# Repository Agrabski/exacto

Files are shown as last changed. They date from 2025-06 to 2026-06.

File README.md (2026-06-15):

Exacto
======

Rust project for the _Arduino Nano_, powering a reflex sight for airsoft guns with an integrated ballistic computer.

## Build Instructions
1. Install prerequisites as described in the [`avr-hal` README] (`avr-gcc`, `avr-libc`, `avrdude`, [`ravedude`]).

2. Run `cargo build` to build the firmware.

3. Run `cargo run` to flash the firmware to a connected board.  If `ravedude`
   fails to detect your board, check its documentation at
   <https://crates.io/crates/ravedude>.

4. `ravedude` will open a console session after flashing where you can interact
   with the UART console of your board.

[`avr-hal` README]: https://github.com/Rahix/avr-hal#readme
[`ravedude`]: https://crates.io/crates/ravedude

## License
Licensed under the GNU General Public License, Version 3 or (at your option)
any later version ([LICENSE](LICENSE) or <https://www.gnu.org/licenses/gpl-3.0.html>).

## Contribution
Unless you explicitly state otherwise, any contribution intentionally submitted
for inclusion in the work by you shall be licensed under the GPL-3.0 license,
without any additional terms or conditions.

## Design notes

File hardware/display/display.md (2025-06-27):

| Pin  | Description |
|---|---|
| RES  | Reset, low active |
| DC | Data/Command selection (high for data, low for command) |
| CS | Chip selection, low active |
| CLK  | Clock input |
| DIN  | Data input |
| GND  | Ground |
| VCC  | Power (3.3V / 5V input) |

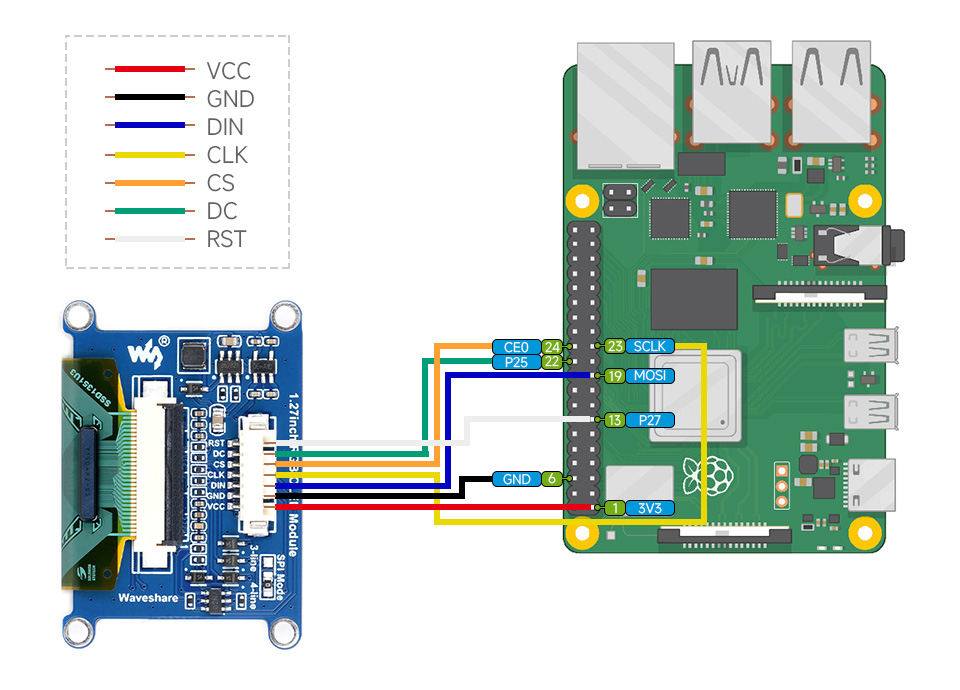
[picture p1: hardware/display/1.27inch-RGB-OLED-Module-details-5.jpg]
Display Pinout Diagram


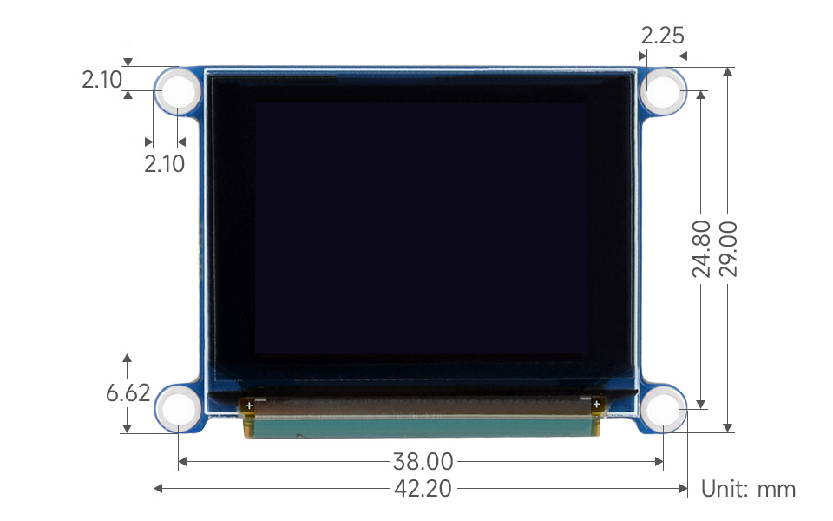
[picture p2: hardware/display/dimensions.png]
Display dimensions


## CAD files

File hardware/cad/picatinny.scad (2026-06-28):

// ============================================================
// Picatinny rail connector — MIL-STD-1913  (TWO-PART clamp)
//
//   picatinny_clamp_body(length)  female clamp FIXED half — ceiling +
//                             right (fixed) jaw + recoil lug.  Built
//                             "hanging": its flat MOUNTING FACE is at z=0
//                             and it extends DOWN, so it unions straight
//                             onto the underside of a part at z=0.
//   picatinny_clamp_bar(length)   the separate, removable LEFT jaw.  Two
//                             cross-bolts pull it toward the body.
//
// The clamp CAPTURES the rail's dovetail: the rail is widest at the 45°
// clamping shoulders, with an undercut below.  Both jaws hook under that
// undercut so the rail can't drop out.  Mounting (mid-rail, no end needed):
// hook the fixed right jaw on the rail, swing the rail up under the
// ceiling, fit the bar onto the left shoulder, then tighten the 2 cross-
// bolts (heads on the bar, running ALL THE WAY THROUGH the clamp into
// brass inserts pressed into the far/outer face of the body) to clamp.
// A recoil lug drops into a transverse slot to take recoil.
// ============================================================

// ── MIL-STD-1913 profile (widest at the shoulders, undercut below) ──
pic_width      = 21.20;  // max width across the clamping shoulders
pic_top_w      = 15.60;  // width of the top flat
pic_body_w     = 15.60;  // width of the rail body / neck (below undercut)
pic_bevel      = (pic_width - pic_top_w) / 2;   // 2.80, 45° run
pic_neck_z     =  1.00;  // body height below the undercut
pic_shoulder_z = pic_neck_z + pic_bevel;        // 3.80, widest clamping line
pic_top_z      = pic_shoulder_z + pic_bevel;    // 6.60, rail top
pic_slot_w     =  5.35;  // recoil-groove width
pic_slot_pitch = 10.00;  // recoil-groove pitch
pic_slot_depth =  2.00;  // recoil-groove depth from the top flat

// ── Clamp / fit ──────────────────────────────────────────────
pic_clear     = 0.30;    // slide-fit clearance on the channel
pic_ceil_t    = 5.00;    // ceiling thickness above the rail top
                         // (tall enough for the cross-bolts to run through)
pic_jaw_t     = 6.00;    // side-jaw thickness
pic_clamp_w   = pic_width + 2 * pic_jaw_t;   // 33.20 overall clamp width
pic_clamp_top = pic_top_z + pic_ceil_t;      // 11.60 mount-face height

// Two-part split: a vertical plane at the rail's left-top edge separates
// the removable bar (left) from the fixed body (right).
pic_split_x   = -pic_top_w / 2;  // -7.80 mating plane
pic_split_gap = 0.50;            // gap so the bolts can draw the bar inward

// Cross-bolts (2): head on the bar (outer left), the bolt runs all the way
// through the bar AND the body, and threads into a brass insert pressed into
// the body's outer (right) face — on the opposite side from the bolt head.
pic_bolt_clear     = 4.30;  // M4 through-bolt clearance (bar + body)
pic_bolt_insert_d  = 6.00;  // M4 brass insert OD (far face of body)
pic_bolt_insert_depth = 6.00;

// Locating pins (2): round bosses on the body's mating face that drop into
// clearance holes in the bar.  They fix the bar's fore/aft (Y) and vertical
// (Z) position relative to the body, so the two clamp halves can't shift out
// of alignment — while still letting the cross-bolts draw the bar inward (X).
pic_loc_pin_d   = 3.00;   // boss diameter
pic_loc_pin_len = 4.00;   // protrusion from the body mating face
pic_loc_clear   = 0.25;   // radial clearance of the bar's locating hole

$fn = 48;

// Rail cross-section (X = width, second coord = height above base).
// Body -> flare OUT to the widest shoulder (undercut) -> bevel IN to top.
function _pic_profile() = [
  [-pic_body_w / 2, 0],
  [ pic_body_w / 2, 0],
  [ pic_body_w / 2, pic_neck_z],
  [ pic_width / 2, pic_shoulder_z],
  [ pic_top_w / 2, pic_top_z],
  [-pic_top_w / 2, pic_top_z],
  [-pic_width / 2, pic_shoulder_z],
  [-pic_body_w / 2, pic_neck_z],
];

// Extrude the (optionally grown) rail profile along +Y, base at z=0.
module _pic_extrude(length, grow = 0) {
  translate([0, length, 0])
    rotate([90, 0, 0])
      linear_extrude(height = length)
        offset(r = grow)
          polygon(_pic_profile());
}

// Bolt height: mid-way up the ceiling band (above the rail top, so the
// bolts run through solid material clear of the channel).
function _pic_bolt_z() = pic_top_z + pic_ceil_t / 2;

// Locating-pin Y positions — shared by the body (bosses) and the bar
// (clearance holes) so they always line up.  Kept well clear of the bolts.
function _pic_loc_yy(length) = [length * 0.15, length * 0.85];

// Whole (un-split) clamp solid in "up" coords: jaw+ceiling block minus the
// rail channel, plus the recoil lug.
module _clamp_solid_up(length) {
  difference() {
    translate([-pic_clamp_w / 2, 0, pic_neck_z])
      cube([pic_clamp_w, length, pic_clamp_top - pic_neck_z + 0.2]);
    translate([0, -1, 0]) _pic_extrude(length + 2, pic_clear);
  }
  // recoil lugs — one tooth per rail slot, as many as fit at the slot
  // pitch, centred along the length (all stay with the fixed body)
  lug_w  = pic_slot_w - 2 * pic_clear;
  n_lugs = max(1, floor((length - lug_w) / pic_slot_pitch) + 1);
  for (i = [0 : n_lugs - 1])
    translate([-6,
               length / 2 + (i - (n_lugs - 1) / 2) * pic_slot_pitch - lug_w / 2,
               pic_top_z - pic_slot_depth + pic_clear])
      cube([12, lug_w, pic_slot_depth + 0.6]);
}

// ── Fixed body (hanging: mount face at z=0, body below) ──────
module picatinny_clamp_body(length) {
  bolt_z = _pic_bolt_z();
  translate([0, 0, -pic_clamp_top + 0.2]) {
    difference() {
      // keep everything right of the split plane (+ gap)
      intersection() {
        _clamp_solid_up(length);
        translate([pic_split_x + pic_split_gap, -1, pic_neck_z - 1])
          cube([pic_clamp_w, length + 2, pic_clamp_top + 2]);
      }
      for (yy = [length * 0.28, length * 0.72]) {
        // through-bolt clearance: from the mating face all the way out the
        // far (right) face, so the screw passes fully through the body
        translate([pic_split_x - 1, yy, bolt_z])
          rotate([0, 90, 0]) cylinder(d = pic_bolt_clear, h = pic_clamp_w);
        // brass insert pressed into the OUTER (right) face — opposite the head
        translate([pic_clamp_w / 2 - pic_bolt_insert_depth, yy, bolt_z])
          rotate([0, 90, 0]) cylinder(d = pic_bolt_insert_d, h = pic_bolt_insert_depth + 0.2);
      }
    }
    // locating bosses — protrude from the mating face toward the bar
    for (yy = _pic_loc_yy(length))
      translate([pic_split_x + pic_split_gap, yy, bolt_z])
        rotate([0, -90, 0]) cylinder(d = pic_loc_pin_d, h = pic_loc_pin_len);
  }
}

// ── Removable bar / left jaw (same coord frame as the body) ──
module picatinny_clamp_bar(length) {
  bolt_z = _pic_bolt_z();
  translate([0, 0, -pic_clamp_top + 0.2])
    difference() {
      // keep everything left of the split plane
      intersection() {
        _clamp_solid_up(length);
        translate([-pic_clamp_w / 2 - 1, -1, pic_neck_z - 1])
          cube([pic_split_x - (-pic_clamp_w / 2 - 1), length + 2, pic_clamp_top + 2]);
      }
      // bolt clearance (head bears on the outer left face — no counterbore)
      for (yy = [length * 0.28, length * 0.72])
        translate([-pic_clamp_w / 2 - 0.1, yy, bolt_z])
          rotate([0, 90, 0]) cylinder(d = pic_bolt_clear, h = pic_clamp_w / 2 + 2);
      // locating holes — receive the body's bosses; bored deeper than the
      // boss reaches so the bolts can still pull the bar fully inward
      for (yy = _pic_loc_yy(length))
        translate([pic_split_x + pic_split_gap, yy, bolt_z])
          rotate([0, -90, 0])
            cylinder(d = pic_loc_pin_d + 2 * pic_loc_clear,
                     h = pic_split_gap + pic_loc_pin_len + 1.0);
    }
}

// ── Demo (ignored when this file is `use`d) ──────────────────
picatinny_clamp_body(40);
color("orange") picatinny_clamp_bar(40);

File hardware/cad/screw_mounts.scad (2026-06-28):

// ============================================================
// Screw mounts — reusable brass-insert + screw-hole cutters
//
// Two negative-geometry modules, meant to be subtracted (difference())
// from a part.  They are the matched halves of one fastened joint:
//
//   insert_hole(size)        bore for a brass heat-set insert, pressed
//                            into the part that the screw threads INTO.
//   screw_hole(size, length) clearance hole in the COMPLEMENTARY part the
//                            screw passes THROUGH — exact screw-body bore
//                            that tapers out (countersink) into the head.
//
// `size` is "M2" or "M3".  Dimensions for the inserts match those already
// used in sight_housing.scad (M2: ø3.20 × 4.0; M3: ø4.00 × 5.0).
//
// Orientation convention (both modules):
//   The mouth of the hole sits at the LOCAL ORIGIN on the Z=0 plane and
//   the hole bores DOWNWARD into -Z, i.e. the fastener is imagined entering
//   from +Z.  Each cutter pokes +0.1 mm past Z=0 so the Boolean cleanly
//   breaks the surface.  translate()/rotate() the call to place it on the
//   real face, exactly like the bores in sight_housing.scad.
//
//   insert_hole : insert is pressed in from +Z; bore is +Z-deep into stock.
//   screw_hole  : head sits flush at Z=0 (countersunk), body bores to -Z.
// ============================================================

// ── Fastener table ───────────────────────────────────────────
// One row per screw size.  Head thickness is the user-specified value
// (M3 = 1.75 mm, M2 = 1.50 mm); head diameter is the user-specified
// countersunk flat-head OD (M3 = 5.8, M2 = 4.0).  Body diameter is the
// nominal thread OD — the screw hole uses this EXACTLY (see screw_hole()).
function screw_body_d(size) =
  size == "M3" ? 3.00 :
  size == "M2" ? 2.00 : undef;

function screw_head_d(size) =
  size == "M3" ? 5.80 :
  size == "M2" ? 4.00 : undef;

function screw_head_t(size) =
  size == "M3" ? 1.75 :
  size == "M2" ? 1.50 : undef;

// Brass heat-set insert bore (outer dia + length) — values shared with
// sight_housing.scad's insert_d / insert_depth (M2) and join_insert_d /
// join_insert_depth (M3).
function insert_bore_d(size) =
  size == "M3" ? 4.00 :
  size == "M2" ? 3.20 : undef;

function insert_bore_depth(size) =
  size == "M3" ? 5.00 :
  size == "M2" ? 4.00 : undef;

// ── Brass-insert bore ────────────────────────────────────────
// Pocket for a heat-set insert, pressed in from +Z.  Bores `depth` into
// -Z (default = the size's standard insert length) and pokes 0.1 mm past
// the Z=0 face so the cut breaks the surface cleanly.
//   depth : override the bore depth (mm).  Leave default for the standard
//           insert length.
module insert_hole(size, depth = undef) {
  d = insert_bore_d(size);
  h = depth == undef ? insert_bore_depth(size) : depth;
  translate([0, 0, -h])
    cylinder(d = d, h = h + 0.1);
}

// ── Screw clearance hole + head countersink ──────────────────
// Cut in the complementary part the screw passes THROUGH.  The straight
// bore is EXACTLY the screw-body diameter (plus optional `clearance`,
// default 0 — a true body-diameter hole as requested); the top
// screw_head_t(size) mm flares out as a cone from the body diameter up to
// the full head diameter, so a countersunk head seats flush at Z=0.
//   length    : straight body-bore length below the taper (mm).  Set to
//               the wall/material thickness the screw shank crosses; the
//               taper sits on top of this, the bore pokes 0.1 mm past the
//               far side for a clean break.
//   clearance : added to the body diameter (mm).  Default 0 = exact body
//               diameter.  Use e.g. 0.4 for a free-fit clearance hole.
module screw_hole(size, length, clearance = 0) {
  bd = screw_body_d(size) + clearance; // straight bore = exact body dia (+fit)
  hd = screw_head_d(size);             // countersink mouth = head dia
  ht = screw_head_t(size);             // taper height = head thickness

  union() {
    // straight body-clearance bore, hanging below the taper
    translate([0, 0, -(length + ht)])
      cylinder(d = bd, h = length + 0.1);
    // head countersink: cone flaring from body dia up to head dia
    translate([0, 0, -ht])
      cylinder(d1 = bd, d2 = hd, h = ht);
    // break the top surface above the head mouth
    translate([0, 0, -0.001])
      cylinder(d = hd, h = 0.1);
  }
}

// ── Demo (only renders when this file is opened directly; `use <>`
// imports the modules/functions above and ignores everything below) ──
$fn = 48;
demo_block = 14;
// left: a block with an M3 insert bore;  right: a block with an M3 screw
// hole, sliced so the countersink + body bore are visible.
difference() {
  translate([-demo_block - 2, -demo_block / 2, -demo_block])
    cube([demo_block, demo_block, demo_block]);
  insert_hole("M3");
}
difference() {
  translate([2, -demo_block / 2, -demo_block])
    cube([demo_block, demo_block, demo_block]);
  translate([2 + demo_block / 2, 0, 0])
    screw_hole("M3", demo_block - 4);
}

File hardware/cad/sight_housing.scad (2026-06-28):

// ============================================================
// Exacto Reflex Sight Housing — v5 (EOTech-style, two-part, birdbath optics)
//
// Two screw-joined parts, split at the seam z = body_height (20 mm), PLUS a
// detachable front-lens cartridge:
//   bottom_part()        display holder = screen_body() + joint inserts
//   top_part()           optics holder  = eotech_shroud() + beamsplitter_mount()
//                                         + combiner_index_stops()
//   combiner_cartridge() removable front lens = combiner_frame() + side ears,
//                        bolted into the top part's front channel by 4 side M3
//                        screws and depth-located by 3 rear indexing stops.
//
// Sub-modules:
//   screen_body()         box holding OLED + electronics, display up
//   eotech_shroud()       rectangular window frame — left/right walls,
//                         top hood, front/rear lower lips, sized to
//                         enclose BOTH optics frames
//   beamsplitter_frame()  flat 30/70 plate frame at `beamsplitter_tilt` deg
//   combiner_frame()      curved partial-mirror ("combiner") frame, fixed
//                         vertical (`combiner_tilt` = 90°)
//   beamsplitter_mount()  / combiner_mount()  position each frame in world
//                         space (side arms overlap the frame and merge
//                         into the shroud side walls, same idiom as v4)
//
// Optics — true birdbath, two elements, each hit EXACTLY ONCE (replaces
//   both the v4 single curved combiner lens AND the earlier "same panel
//   hit twice" birdbath topology):
//   display (face up) -> flat 30/70 beamsplitter, fixed 45° relay (1st &
//   only hit) -> curved partial-mirror combiner, fixed VERTICAL 90°
//   (2nd & only hit, exact retro-reflection back the way it came) -> eye,
//   looking back THROUGH the combiner's see-through window.  Both tilts
//   are fixed constants now — no derivation, no sweep.  See the
//   "Birdbath optics" parameter block below for the exact ray-trace.
//
// Joint: the top part's side walls drop below the seam as SKIRTS that lap
//   over rebates on the bottom part's thick side edges.  4 horizontal M3
//   screws (2 per side), placed LOW — under the PCB, in the solid lower
//   body — pin and clamp the lap.  Use M3 x ~12 mm into brass inserts.
//   The left/right edges are thickened (side_edge) to host the inserts.
//
// Forward box: a hollow electronics enclosure extends from the optics head
//   toward the muzzle (box_length), full width, up to the lens-opening
//   height, with a screw-on top lid.  Cable routes UNDER the PCB to a plug
//   opening in the box front face.
//
// Mount: a female MIL-STD-1913 Picatinny clamp (picatinny.scad) is fused
//   to the underside and runs the WHOLE length of the sight.
//
// Optics retention: friction fit in the frame pockets + adhesive.  The
// beamsplitter frame is fused into the top part; the COMBINER frame is a
// detachable cartridge (combiner_cartridge()) bolted in from the sides, so the
// front lens can be serviced/swapped without reprinting the optics head.
//
// Set `render_part` below to choose what to render/export.
//
// Display: Waveshare 1.27-inch SSD1351 RGB OLED
//   PCB     42.20 × 29.00 mm  (hardware/display/dimensions.png)
//   Active  38.00 × 24.80 mm
//   Holes   ø2.10, inset 2.25 mm (X) / 2.10 mm (Y) from PCB edge
//
// Birdbath optics (replaces both the old single curved meniscus combiner
// AND the earlier two-hit-same-panel birdbath):
//   Beamsplitter: flat 30/70 reflective sheet, beamsplitter_optic_width x
//                 beamsplitter_optic_height, FIXED 45° relay near the
//                 display — redirects the vertical beam to exactly
//                 horizontal, nothing more.
//   Combiner:     curved partial mirror, combiner_optic_width x
//                 combiner_optic_height, single cylindrical curvature
//                 combiner_radius, FIXED VERTICAL (combiner_tilt = 90°) —
//                 the element the eye actually looks through, both for the
//                 real target and the reflected reticle.
//   See the "Birdbath optics" parameter block for the full derivation.
// ============================================================

// ┌─────────────────────────────────────────────────────────────┐
// │  beamsplitter_tilt = beamsplitter tilt from horizontal —      │
// │  FIXED at 45°.  combiner_tilt = combiner tilt — FIXED at 90°  │
// │  (vertical).  Both are pinned per explicit design decision    │
// │  (topology "c") — NOT reprint-tunable sweep parameters any    │
// │  more.  Changing either invalidates the whole fold derivation │
// │  below.                                                       │
// └─────────────────────────────────────────────────────────────┘
use <picatinny.scad>
use <screw_mounts.scad>

beamsplitter_tilt = 45; // beamsplitter tilt from horizontal, deg — FIXED, do not sweep (was 35–65 in the rejected topology)

// Which piece to render/export: "both" (assembled), "top", "bottom",
// "combiner" (detachable front-lens cartridge), "bar" (removable Picatinny
// clamp jaw), "lid" (box top lid)
render_part = "both";

// Forward electronics box (extends from the optics head toward the muzzle).
box_length = 80.00; // box length, front-to-rear (8 cm)

// ── Display (Waveshare 1.27" SSD1351 OLED) ───────────────────
display_pcb_width = 42.20; // OLED carrier PCB width  (X)
display_pcb_height = 29.00; // OLED carrier PCB height (Y)
display_pcb_thickness = 1.80; // OLED carrier PCB thickness (Z)
display_active_width = 38.00; // visible/active screen width  (X)
display_active_height = 24.80; // visible/active screen height (Y)
display_hole_dia = 2.10; // PCB clearance-hole dia (datasheet); not used for body bores
display_hole_inset_x = 2.25; // mounting-hole inset from the PCB edge, X
display_hole_inset_y = 2.10; // mounting-hole inset from the PCB edge, Y
display_fit_clearance = 0.10; // gap on EVERY side of the OLED PCB in its pocket (X/Y edges + Z floor)

// ── Fasteners ────────────────────────────────────────────────
// All screw/insert geometry now comes from screw_mounts.scad — its
// insert_hole()/screw_hole() cutters plus the shared M2/M3 fastener table
// are the single source of truth (no local diameter/depth constants).
//   PCB        : M2, screw from the top into inserts below the pocket.
//   Part joint : M3, 4 horizontal screws through the skirts into edge inserts.
//   Box lid    : M3, 4 vertical screws through the lid into boss inserts.
m3_clearance_fit = 0.40; // added to the M3 body dia for a free-fit through-hole (skirts + lid)
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

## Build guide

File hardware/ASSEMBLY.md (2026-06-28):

# Exacto Reflex Sight — Parts List & Assembly

Build guide for the **XM-1E1** housing
defined in [`cad/sight_housing.scad`](cad/sight_housing.scad).

> **Versioning:** `XM-<gen>E<rev>`. The `E<rev>` number is incremented
> **only after a revision has been sent to print** — not on ordinary design
> edits. Current revision: **XM-1E1**.

The sight is a two-part printed housing that holds a small OLED, folds its
image through a birdbath relay (flat beamsplitter → curved partial-mirror
combiner), and clamps to a MIL-STD-1913 Picatinny rail. All electronics
other than the display live in a forward box with a removable lid.

Overall envelope: **58.2 mm wide × 114 mm long × ~50 mm tall** (rail clamp
adds ~11.6 mm below).

---

## 1. Printed parts

Export each by setting `part=` at the top of `sight_housing.scad` (or
`openscad -D 'part="…"'`) and slicing the resulting STL.

| `part` | Component | Qty | Notes |
|---|---|-----|---|
| `bottom` | Bottom part — display holder + forward electronics box + **fixed** Picatinny jaw | 1 | Hosts the OLED pocket, cable channel, and all brass inserts except the lid/combiner |
| `top` | Top part — optics shroud + beamsplitter mount + combiner mount | 1 | Holds both optical elements |
| `bar` | Picatinny clamp bar (removable left jaw) | 1 | Pulled in by 2 cross-bolts |
| `lid` | Forward-box top lid | 1 | Screws onto the box bosses |

`part="both"` renders the full assembled preview (all four parts in place)
for checking fit; it is not a printable export.

### Print recommendations
- Material: PLA/PETG (PETG or ABS/ASA if the sight will see sun/heat).
- Layer height ≤ 0.2 mm around the optic pockets for a clean friction fit.
- Suggested orientation: print **bottom** and **top** on their flat seam
  face (z = 20 mm split plane) so the lap joint and insert bores come out
  true; print the **lid** flat; print the **bar** on its outer flat face.
- The combiner pocket has a shallow (~1 mm) cylindrical curve — no supports
  needed, but don't over-extrude or the optic won't seat flat.

---

## 2. Optical elements (not printed)

| Item | Size | Qty | Notes |
|---|---|-----|---|
| Plate beamsplitter, 30/70 (R/T) | 32 × 30 mm, 2.0 mm thick | 1 | Flat sheet. Drops into the angled (45°) frame pocket from the front (+Y) face |
| Collimating combiner lens | 34 × 24 mm stadium (rounded R16.97 ends), 2.74 mm thick | 1 | The previously-used lens ([`lens/lense.avif`](lens/lense.avif)). Sits vertical; drops into the front cartridge pocket from the front (+Y) face |

Both are retained by friction fit in their pockets **plus adhesive** (no set
screws — the merged side arms bury any screw access). A ~1.5 mm rim laps each
optic at the rear; the eye looks straight through both windows.

### Recommended / DIY materials

A true cylindrical R≈120 mm partial-mirror combiner is not a common catalog
part, so the optics are the part that drives sourcing. Cheap, hobby-tool
options below; all are knife/scorer/heat-gun workable with no custom optics
order (total optics cost ~$15–30).

**Beamsplitter (flat — the easy one):**
- **Best match:** 70/30 (or 30/70) **teleprompter glass** — dielectric
  partial-mirror film on glass. Score and snap to 32 × 30 mm. ~2 mm thick,
  which matches the pocket. ~$10–20.
- **Cheaper alt:** **two-way ("one-way") mirror acrylic** — saw/laser
  cuttable, won't shatter. Reflectivity is nearer 50/50 and less spectrally
  even, but fine for a prototype. ~$5–15.
- If using thin film-on-PET, laminate it to a 2.0 mm clear carrier so it
  seats flush under the retaining lip. Avoid fragile pellicle beamsplitters
  for a DIY build.
- **Orientation (ghost suppression):** teleprompter glass is partially
  reflective on one face and AR-coated on the other. Mount it with the
  **AR-coated face outward** (toward the real world) so the second surface
  doesn't throw a ghost/double image. This is the standard DIY-AR (Project
  North Star) practice.

**Combiner (curved partial mirror — the hard one):**
- **Recommended DIY:** thermoform **two-way mirror acrylic** over a
  3D-printed **R = 120 mm convex cylindrical (or spherical) form**. Heat to
  ~120–160 °C (heat gun / oven) and slump. Sag over the 32 mm aperture is
  only ~1.07 mm, so the curve is gentle and forgiving. Reflective face goes
  **concave / rear** (−Y) per Step 2 below.
- **Acceptable substitute:** a **spherical** R≈120 mm partial mirror — over a
  32 mm window the difference from cylindrical is minor and spherical forms
  are easier to make/buy.
- **Exact but not cheap:** the serious DIY-AR route. Either a
  cylindrical/spherical concave mirror R = 120 mm (f ≈ 60 mm) with a partial
  coating from an optics supplier (Edmund/Thorlabs), or a **CNC / diamond-
  turned solid PMMA reflector** (the method Leap Motion's Project North Star
  uses, and what vendors like CombineReality / Smart Prototyping sell). Tens
  of dollars plus likely a custom coating, but the surface accuracy is what
  makes the image distortion-free.
  - **How to obtain one (made to spec):** there is no off-the-shelf optic
    for this surface — ready-made AR combiners (e.g. Project North Star
    reflectors) are large freeform/ellipsoidal parts and do **not** match the
    32 × 32 mm, R = 120 mm cylinder, so don't try to adapt one. Instead,
    export the combiner surface from
    [`cad/sight_housing.scad`](cad/sight_housing.scad) as a STEP/STL and send
    it to an online CNC service (PCBWay, Xometry, Protolabs, or a local shop)
    requesting **optical-grade PMMA, machined then vapor-polished** for the
    32 × 32 mm, R = 120 mm concave face. Finish with a partial-mirror
    treatment: a sputter/optics house can apply a real beamsplitter coating,
    or for a budget build apply two-way mirror film / a light spray-on
    "mirror tint" to the convex rear face. Diamond-turning gives the best
    surface but needs a specialist shop (e.g. a custom-optics fabricator) and
    raises cost into the hundreds.
- **Salvage:** curved combiners from dead red-dot sights or cheap car-HUD
  reflectors are already partial mirrors, but their radius won't be 120 mm —
  only viable if you re-derive the optical block.

> **Important:** the model's ~50 mm eye relief and reticle collimation assume
> the **120 mm combiner radius** and the **concave-rear** orientation.
> Substituting a different curve (e.g. a salvaged combiner) invalidates the
> fold; re-check the optical block in
> [`cad/sight_housing.scad`](cad/sight_housing.scad) first.
>
> Combiner reflectivity is a trade-off: too high dims the see-through target,
> too low washes out the reticle. Two-way acrylic (~50/50) is a fine starting
> point — tune by swapping film/coating grades.
>
> **Ghosting:** a thermoformed two-way-acrylic combiner has no AR coating on
> either face, so expect some secondary (ghost) reflection — the known cost
> of the cheap route. DIY-AR builds (Project North Star) AR-coat the outer
> (convex) combiner face to kill it; a CNC/bought reflector can come coated.
> The small 32 mm aperture and gentle R = 120 mm curve keep distortion low,
> which is the one thing working in the thermoform route's favor.

---

## 3. Electronics

| Item | Qty | Notes |
|---|-----|---|
| Waveshare 1.27" SSD1351 RGB OLED module | 1 | PCB 42.20 × 29.00 mm; active area 38.0 × 24.80 mm faces up |
| Microcontroller (Arduino Nano or equiv.) | 1 | Lives in the forward box; `body_height` is sized for a Nano + wiring |
| Battery + USB / power board | 1 | Forward box; cable exits the box front plug opening (14 × 9 mm) |
| Ribbon/flying lead, OLED → MCU | 1 | Routes **under** the PCB, down the cable channel, into the forward box |

---

## 4. Fasteners

All screws are **countersunk (flat-head)** except the PCB screws (head bears
on the PCB) and the Picatinny cross-bolts (head bears on the bar's outer
face). Insert bores and countersinks are generated by
[`cad/screw_mounts.scad`](cad/screw_mounts.scad) and `cad/picatinny.scad`.

| Joint | Screw | Qty | Brass heat-set insert | Qty |
|---|---|-----|---|-----|
| PCB → body | M2 pan/cheese-head × **8 mm** | 4 | M2 (ø3.2 × 4 mm bore) | 4 |
| Top ↔ bottom side joint | M3 countersunk × **12 mm** (horizontal, 2 per side) | 4 | M3 (ø4.0 × 5 mm bore) | 4 |
| Forward-box lid | M3 countersunk × **12 mm** (vertical) | 2 | M3 (ø4.0 × 5 mm bore) | 2 |
| Picatinny clamp cross-bolts | M4 socket-cap × ~16 mm (horizontal) | 2 | M4 (ø6.0 × 6 mm bore) | 2 |

Screw lengths chosen from the available stock (M2: 8/20 mm; M3: 12/16/20 mm)
as the shortest that fully engages each insert. The M2 × 8 mm engages the
full 4 mm insert; both M3 × 12 mm leave the tip seated in solid material
behind the insert (no breakthrough into a cavity).

**Totals:** 4× M2 + 6× M3 + 2× M4 screws; 4× M2, 6× M3, 2× M4 brass inserts.

> Head geometry the model cuts for: M2 head ø4.0 mm / 1.5 mm thick,
> M3 head ø5.8 mm / 1.75 mm thick (countersink cones). Buy flat-head screws
> matching these so they seat flush.

---

## 5. Assembly

### Step 1 — Press the heat-set inserts
With a soldering iron set for brass inserts, press into the **bottom part**:
- 4× **M2** into the PCB-pocket floor bores (one near each PCB corner).
- 4× **M3** into the side-edge bores (2 per side, low, under the PCB line).
- 2× **M3** into the forward-box lid bosses (front inside corners).
- 2× **M4** into the fixed Picatinny jaw's mating face.

Keep inserts square to the bore; let them cool before loading.

### Step 2 — Bond the optics into the top part
- Seat the **beamsplitter** sheet into its 45° pocket from the front face;
  dab adhesive on the rim. It should sit flush under the retaining lip.
- Seat the **collimating combiner lens** into its vertical stadium pocket
  from the front (+Y) face; it sits flush under the rear retaining rim. Bond.
- Let the adhesive fully cure before further handling.

### Step 3 — Fit and wire the display
- Solder/attach the OLED's flying lead and route it so it will exit the PCB
  underside.
- Drop the OLED into the top pocket of the **bottom part**, active area up
  through the window.
- Fasten with the 4× **M2** screws from the top into the PCB inserts. Snug
  only — don't crack the PCB.
- Route the ribbon down through the cable channel toward the forward box.

### Step 4 — Populate the forward box
- Place the MCU and battery in the forward box.
- Bring the display cable and any external power lead to the front plug
  opening.

### Step 5 — Join the two halves
- Lower the **top part** onto the **bottom part**: the top's side skirts lap
  over the rebates on the bottom's side edges.
- Drive the 4× **M3** countersunk screws horizontally through the skirts into
  the edge inserts (2 per side). Tighten evenly to clamp the lap.

### Step 6 — Close the forward box
- Set the **lid** onto the box bosses.
- Secure with the 2× **M3** countersunk screws.

### Step 7 — Mount to the Picatinny rail
- Hook the fixed (body) jaw onto one rail shoulder.
- Swing the rail up under the clamp ceiling; the recoil lug drops into a
  transverse rail slot.
- Fit the removable **bar** onto the opposite shoulder.
- Run the 2× **M4** cross-bolts through the bar into the body inserts and
  tighten alternately until the clamp grips. Do not overtighten plastic.

### Step 8 — Check
- Confirm the OLED image appears centered in the combiner window and the
  reticle/target are co-aligned (the level exit ray is fixed by the 45°
  beamsplitter + vertical combiner geometry).
- Verify nothing fouls the rail and the clamp holds under hand pressure.

---

## Reference dimensions (from the model)

| Parameter | Value |
|---|---|
| Body (display head) | 58.2 W × 34 D × 20 H mm |
| Forward box length | 80 mm |
| Total rail length | 114 mm |
| Split plane (seam) | z = 20 mm |
| Beamsplitter tilt | 45° (fixed) |
| Combiner tilt | 90° / vertical (fixed) |
| Unfolded optical path | 60 mm (combiner R = 120 mm) |
| Nominal eye relief | ~50 mm |

See the header comment in `cad/sight_housing.scad` for the full optical
derivation.

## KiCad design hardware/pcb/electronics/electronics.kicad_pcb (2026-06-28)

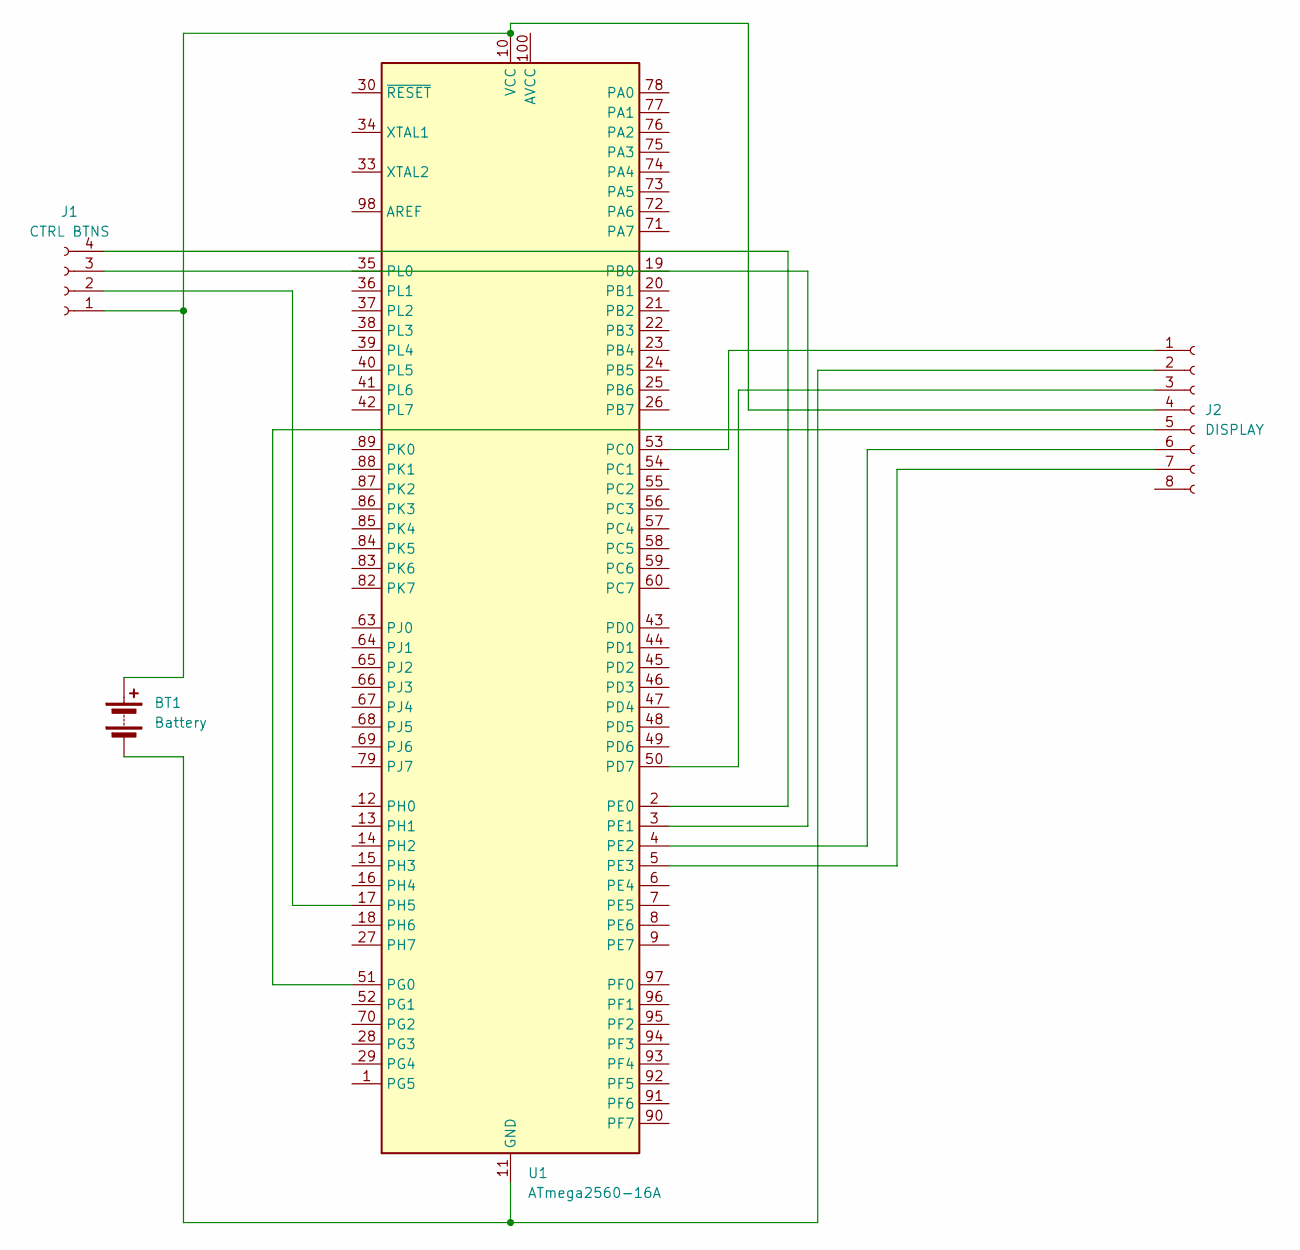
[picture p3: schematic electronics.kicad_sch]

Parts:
BT1: Battery; JWT_A3963_1x02_P3.96mm_Vertical
J1: CTRL BTNS; JST_EH_S4B-EH_1x04_P2.50mm_Horizontal
J2: DISPLAY; JST_EH_S8B-EH_1x08_P2.50mm_Horizontal
U1: ATmega2560-16A; TQFP-100_14x14mm_P0.5mm

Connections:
unnamed: BT1.1 (+), J1.1, J2.4, U1.10 (VCC), U1.31 (VCC), U1.61 (VCC), U1.80 (VCC)
unnamed: BT1.2 (-), J2.2, U1.11 (GND), U1.32 (GND), U1.62 (GND), U1.81 (GND), U1.99 (GND)
unnamed: J1.2, U1.17 (PH5)
unnamed: J1.3, U1.3 (PE1)
unnamed: J1.4, U1.2 (PE0)
unnamed: J2.1, U1.53 (PC0)
unnamed: J2.3, U1.50 (PD7)
unnamed: J2.5, U1.51 (PG0)
unnamed: J2.6, U1.4 (PE2)
unnamed: J2.7, U1.5 (PE3)

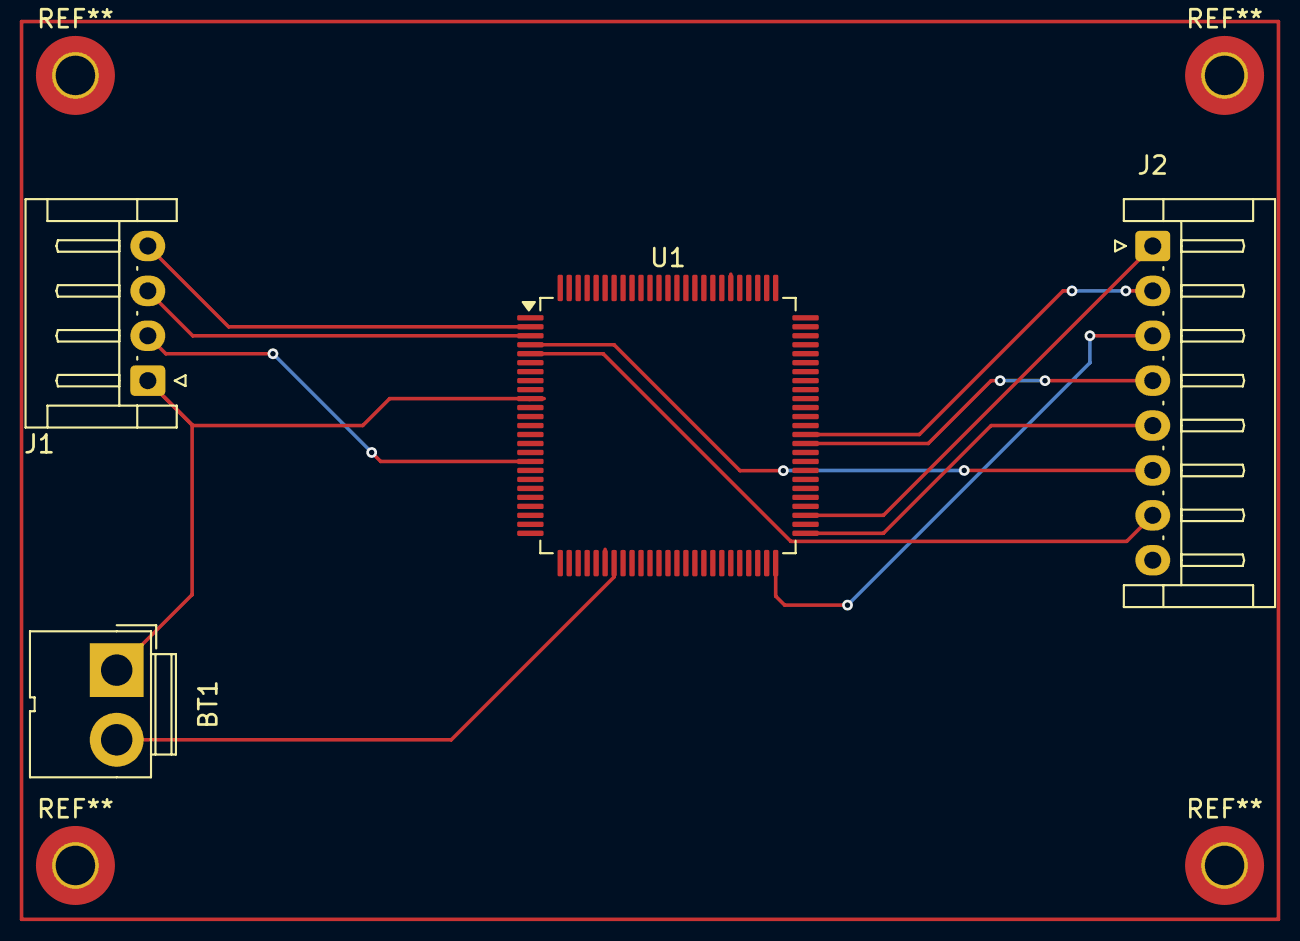
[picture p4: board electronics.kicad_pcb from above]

Board: 2 copper layers, 4 parts (0 on the bottom side), 10 nets.

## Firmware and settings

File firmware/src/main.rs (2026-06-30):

#![no_std]
#![no_main]
#![feature(abi_avr_interrupt)]
mod buttons;
mod display_initialisation;
mod embedded_graphics_transform;
mod settings;
mod sight;
mod text;

use core::fmt::Debug;

use ::ballistic_calculator::CalculatorConfiguration;
use arduino_hal::default_serial;
use embedded_graphics::prelude::{DrawTarget, Primitive};
use embedded_graphics::primitives::{Line, PrimitiveStyleBuilder};
use embedded_graphics::Drawable;
use embedded_graphics::{
    pixelcolor::Rgb565,
    prelude::{Point, RgbColor},
};
use embedded_graphics_core::{prelude::Size, primitives::Rectangle};

use crate::display_initialisation::create_display;
use crate::sight::Sight;

#[arduino_hal::entry]
fn main() -> ! {
    let dp = arduino_hal::Peripherals::take().unwrap();
    let pins = arduino_hal::pins!(dp);
    // Hardware SPI on the ATmega2560 lives on PB0-PB3 (Mega pins D53/D52/D51/D50).
    let cs = pins.d53.into_output(); // PB0 / SS
    let clk = pins.d52.into_output(); // PB1 / SCK
    let din = pins.d51.into_output(); // PB2 / MOSI
    let rst = pins.d4.downgrade().into_output();
    let dc = pins.d5.downgrade().into_output();
    let miso = pins.d50.into_pull_up_input(); // PB3 / MISO

    let mut interface = create_display(dp.SPI, cs, clk, din, rst, dc, miso);

    display_startup_screen(&mut interface);

    let mut sight = Sight {
        x_zero: 0,
        y_zero: 0,
        battery_power: 15,
        range: 33,
        last_range: 0,
        drift: Point::default(),
        configuration: CalculatorConfiguration::default(),
        time_of_flight_ms: 0,
    };
    // Buttons: active-low with internal pull-ups. up=d2 (INT4), down=d3 (INT5),
    // select=d18 (INT3). The interrupt vectors read the port directly, so the pin
    // handles are dropped once the pull-ups/DDR are latched.
    let _up = pins.d2.into_pull_up_input();
    let _down = pins.d3.into_pull_up_input();
    let _select = pins.d18.into_pull_up_input();

    // Falling-edge sense (ISCx1:ISCx0 = 0b10) on INT3/INT4/INT5, then unmask them.
    dp.EXINT.eicra.modify(|_, w| w.isc3().val_0x02()); // INT3 (d18)
    dp.EXINT
        .eicrb
        .modify(|_, w| w.isc4().val_0x02().isc5().val_0x02()); // INT4 (d2), INT5 (d3)
    dp.EXINT.eifr.write(|w| w.bits(0b0011_1000)); // clear any pending INT3/4/5 flags
    dp.EXINT.eimsk.write(|w| w.bits(0b0011_1000)); // enable INT3/4/5
    unsafe { avr_device::interrupt::enable() };

    let mut serial = default_serial!(dp, pins, 57600);

    let mut last_update_loop = 0;
    let mut settings_state = settings::SettingsState::new();
    interface.clear_oled();
    let mut settings_were_opened = false;
    ufmt::uwriteln!(&mut serial, "start1").ok();
    display_sight(&mut interface, &sight);
    loop {
        let last_sight = sight.clone();
        last_update_loop += 1;
        let event = buttons::poll();
        let settings_was_updated = settings_state.update(&mut sight, event);
        if settings_was_updated || settings_state.is_open() {
            if settings_was_updated {
                interface.clear_oled();
                settings_state.draw(&mut interface, &sight);
                last_update_loop = 8000;
                settings_were_opened = true;
            }
        } else {
            if let Some(event) = event {
                if event == buttons::ButtonEvent::Up {
                    sight.range += 5;
                }
                if event == buttons::ButtonEvent::Down && sight.range >= 5 {
                    sight.range -= 5;
                }
                sight.update();
            }
            if last_sight != sight || settings_were_opened {
                interface.clear_oled();
                display_sight(&mut interface, &sight);
                ufmt::uwriteln!(&mut serial, "TOF {}", sight.time_of_flight_ms).ok();
                last_update_loop = 0;
                settings_were_opened = false;
            }
        }
    }
}

fn display_startup_screen<T>(interface: &mut T)
where
    T: DrawTarget<Color = Rgb565, Error: Debug>,
{
    let dimensions = interface.bounding_box().size;
    text::draw_text(
        interface,
        "EXACTO XM1E0",
        Point::new((dimensions.width / 2 - 12) as i32, 0),
        Rgb565::WHITE,
        Rgb565::BLACK,
    );
    Rectangle::new(Point::new(10, 10), Size::new(40, 30))
        .into_styled(PrimitiveStyleBuilder::new().fill_color(Rgb565::RED).build())
        .draw(interface)
        .unwrap();

    arduino_hal::delay_ms(200);

    Rectangle::new(Point::new(15, 15), Size::new(40, 30))
        .into_styled(
            PrimitiveStyleBuilder::new()
                .fill_color(Rgb565::GREEN)
                .build(),
        )
        .draw(interface)
        .unwrap();

    arduino_hal::delay_ms(200);

    Rectangle::new(Point::new(20, 20), Size::new(40, 30))
        .into_styled(
            PrimitiveStyleBuilder::new()
                .fill_color(Rgb565::BLUE)
                .build(),
        )
        .draw(interface)
        .unwrap();

    arduino_hal::delay_ms(200);
    let line_style = PrimitiveStyleBuilder::new()
        .stroke_color(Rgb565::WHITE)
        .stroke_width(1)
        .build();

    Line::new(
        Point::new(0, 0),
        Point::new(dimensions.width as i32 - 1, dimensions.height as i32 - 1),
    )
    .into_styled(line_style)
    .draw(interface)
    .unwrap();

    Line::new(
        Point::new(0, dimensions.height as i32 - 1),
        Point::new(dimensions.width as i32 - 1, 0),
    )
    .into_styled(line_style)
    .draw(interface)
    .unwrap();

    arduino_hal::delay_ms(500);
}

fn display_sight<T>(interface: &mut T, sight: &Sight)
where
    T: DrawTarget<Color = Rgb565, Error: Debug>,
{
    let mut buffer = *b"PWR: XXX";
    write_value(
        interface,
        sight.battery_power as u16,
        Point::new(0, 90),
        &mut buffer,
    );
    draw_reticle(interface, sight);
}

fn draw_reticle<T>(interface: &mut T, sight: &Sight)
where
    T: DrawTarget<Color = Rgb565, Error: Debug>,
{
    let reticle_size: u32 = 8;
    let center = sight.point_of_aim();
    draw_rectangle(
        interface,
        Rectangle::with_center(center, Size::new(reticle_size, reticle_size)),
    );

    let point_of_impact = sight.calculated_point_of_impact();
    draw_rectangle(
        interface,
        Rectangle::with_center(
            point_of_impact,
            Size::new(reticle_size / 2, reticle_size / 2),
        ),
    );
    let text_position = point_of_impact + Point::new((reticle_size / 2 + 8) as i32, 0);
    let mut buffer = *b"TOF: XXX";
    write_value(
        interface,
        sight.time_of_flight_ms / 10, // tens of miliseconds
        text_position,
        &mut buffer,
    );
    buffer = *b"RNG: XXX";
    write_value(
        interface,
        sight.range as u16,
        text_position + Point::new(0, 6),
        &mut buffer,
    );
}

fn draw_rectangle<T>(interface: &mut T, rectangle: Rectangle)
where
    T: DrawTarget<Color = Rgb565, Error: Debug>,
{
    let r = rectangle.into_styled(
        PrimitiveStyleBuilder::new()
            .stroke_width(1)
            .stroke_color(Rgb565::RED)
            .build(),
    );
    r.draw(interface).unwrap();
}

fn write_value<T>(interface: &mut T, value: u16, position: Point, buffer: &mut [u8])
where
    T: DrawTarget<Color = Rgb565, Error: Debug>,
{
    format_two_digit_16(value as i16, buffer);
    // `buffer` holds ASCII produced by `format_two_digit_16`, so it is valid UTF-8.
    let text = unsafe { core::str::from_utf8_unchecked(buffer) };
    text::draw_text(interface, text, position, Rgb565::WHITE, Rgb565::BLACK);
}

fn format_two_digit_16(num: i16, buf: &mut [u8]) {
    assert!(buf.len() >= 4, "Buffer must be at least 4 bytes long");

    let len = buf.len();
    let abs_num = num.abs() as u16;

    buf[len - 4] = if num < 0 { b'-' } else { b' ' };
    buf[len - 3] = b'0' + ((abs_num / 100) % 10) as u8;
    buf[len - 2] = b'0' + ((abs_num / 10) % 10) as u8;
    buf[len - 1] = b'0' + (abs_num % 10) as u8;
}

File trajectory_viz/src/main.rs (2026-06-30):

//! Interactive BB trajectory visualizer.
//!
//! Plots BB drop vs. downrange distance (0-100 m) for a shot fired parallel to
//! the ground, with live-adjustable parameters. Two curves are overlaid:
//!   * an accurate host-side `f64` forward-Euler simulation, and
//!   * the embedded `ballistic_calculator` (`f32` math) that actually runs on the
//!     device.
//! The divergence between them shows how well the embedded approximation holds up.

use ballistic_calculator::{calculate_drift, CalculatorConfiguration, Float};
use eframe::egui;
use egui_plot::{Legend, Line, Plot, PlotPoints};

/// 6 mm BB.
const BB_RADIUS_M: f64 = 0.003;
const GRAVITY: f64 = 9.81;
/// Muzzle height above the ground (shooter holding the gun), metres.
const START_HEIGHT_M: f64 = 1.8;

/// Adjustable inputs. Elevation is fixed at 0 (fired parallel to the ground).
struct Params {
    bb_weight_g: f64,       // grams
    muzzle_energy_j: f64,   // Joules
    magnus_spin_rad_s: f64, // hop-up backspin (rad/s)
    air_density: f64,       // kg/m^3
    drag_cd: f64,           // dimensionless
}

impl Default for Params {
    fn default() -> Self {
        // Mirrors CalculatorConfiguration::default(): 0.4 g BB, 1.9 J, 15 rad/s,
        // air density 1.8, drag 0.43.
        Self {
            bb_weight_g: 0.40,
            muzzle_energy_j: 1.9,
            magnus_spin_rad_s: 15.0,
            air_density: 1.8,
            drag_cd: 0.43,
        }
    }
}

impl Params {
    fn mass_kg(&self) -> f64 {
        (self.bb_weight_g / 1000.0).max(1e-6)
    }

    fn muzzle_velocity(&self) -> f64 {
        (2.0 * self.muzzle_energy_j / self.mass_kg()).sqrt()
    }
}

struct SimResult {
    /// `[range_m, height_m]` trajectory samples.
    pts: Vec<[f64; 2]>,
    /// `[range_m, time_ms]` time-of-flight samples (same cadence as `pts`).
    tof: Vec<[f64; 2]>,
}

/// Accurate trajectory: forward-Euler integration in the vertical plane.
fn simulate_f64(p: &Params) -> SimResult {
    let r = BB_RADIUS_M;
    let area = std::f64::consts::PI * r * r;
    let m = p.mass_kg();

    let mut x = 0.0_f64;
    let mut y = START_HEIGHT_M;
    let mut vx = p.muzzle_velocity();
    let mut vy = 0.0_f64;

    // Integration step in milliseconds; physics equations use dt_s (seconds).
    let dt_ms = 0.5_f64;
    let dt_s = dt_ms * 1e-3;
    let mut t_ms = 0.0_f64;
    let sample_step = 0.5_f64;
    let mut next_sample = sample_step;

    let mut pts = vec![[0.0, START_HEIGHT_M]];
    let mut tof = vec![[0.0, 0.0_f64]];
    while x < 100.0 && t_ms < 30_000.0 {
        let v = (vx * vx + vy * vy).sqrt().max(1e-9);

        // Drag: Fd = 0.5 * Cd * rho * A * v^2, opposing the velocity vector.
        let drag_accel = 0.5 * p.drag_cd * p.air_density * area * v * v / m;
        let ax_drag = -drag_accel * vx / v;
        let ay_drag = -drag_accel * vy / v;

        // Magnus (mirrors the crate's form 0.5 * rho * r^3 * v * omega), acting
        // perpendicular to velocity; backspin lifts the BB (+y for +x motion).
        let magnus_accel = 0.5 * p.air_density * r * r * r * v * p.magnus_spin_rad_s / m;
        let ax_mag = magnus_accel * (-vy / v);
        let ay_mag = magnus_accel * (vx / v);

        vx += (ax_drag + ax_mag) * dt_s;
        vy += (ay_drag + ay_mag - GRAVITY) * dt_s;
        x += vx * dt_s;
        y += vy * dt_s;
        t_ms += dt_ms;

        if x >= next_sample {
            pts.push([x, y]);
            tof.push([x, t_ms]);
            next_sample += sample_step;
        }
        // Stop once the BB has hit the ground.
        if y < 0.0 {
            break;
        }
    }
    SimResult { pts, tof }
}

struct EmbeddedSimResult {
    pts: Vec<[f64; 2]>,
    /// `[range_m, time_ms]` from the embedded calculator.
    tof: Vec<[f64; 2]>,
}

/// The embedded calculator's view of the trajectory: call `calculate_drift` for
/// each whole-metre range and read back the cumulative vertical drift and TOF.
fn simulate_embedded(p: &Params) -> EmbeddedSimResult {
    let config = CalculatorConfiguration {
        magnus_effect_angular_velocity: p.magnus_spin_rad_s as Float,
        bb_weight: p.mass_kg() as Float,
        muzzle_energy: p.muzzle_energy_j as Float,
        angle_of_elevation: 0.0,
        air_density: p.air_density as Float,
        drag_coefficient: p.drag_cd as Float,
    };

    let mut pts = vec![[0.0, START_HEIGHT_M]];
    let mut tof = vec![[0.0, 0.0_f64]];
    for range in 1..=100 {
        let drift = calculate_drift(&config, range as Float);
        pts.push([range as f64, START_HEIGHT_M + drift.drift_y as f64]);
        tof.push([range as f64, drift.time_of_flight as f64]);
    }
    EmbeddedSimResult { pts, tof }
}

struct App {
    params: Params,
}

impl Default for App {
    fn default() -> Self {
        Self {
            params: Params::default(),
        }
    }
}
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

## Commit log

2025-06-12 switched rst and dc pins to free up interrupt pins
2025-06-12 refactor: update display initialization and add rotary encoder implementation
2025-06-16 first settings prototype
2025-06-27 display h older sketch complete
    [body.FCStd]
2025-06-27 display holder finalised
    [body.FCStd]
2025-06-27 added lense graphic, started lense holder sketch
    [body.FCStd]
2025-06-28 finalised increment 0 CAD design
    [body.FCStd]
2025-07-06 fixed a bunch of stuff
    [main.rs]
2025-07-08 ballistic computer does not crash in tests. Not flashed yet
    [main.rs]
2025-07-09 firmware flashes and does not crash
    [main.rs]
2025-07-13 started designing the scope body from scratch
    [body.FCStd]
2026-05-27 Add OpenSCAD sight housing with adjustable screen-to-lens angle
    Parametric model for 3D printing the reflex sight housing.
    Dimensions taken from hardware/display/dimensions.png (42.20x29.00mm PCB,
    38.00x24.80mm active area). Lens arm pivots on an M3 hinge pin; an arc
    slot (30-60°, 5° detents) and lock bolt let the screen-to-lens angle be
    set at print time or adjusted after assembly.
    https://claude.ai/code/session_01CGtrs7Z3cyJTER9gnwPHDv
    [sight_housing.scad]
2026-05-27 Simplify sight housing: fixed angle set at design time, no hinge
    Replaced the hinge + arc-slot mechanism with a single `angle` parameter.
    The arm and body are one solid printed piece; change the parameter,
    re-export the STL, and reprint to get a different angle.
    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
    [sight_housing.scad]
2026-05-27 Update lens dimensions from hardware/lens/lense.avif
    Collimating lens: 24×34 mm, 2.74 mm thick, R16.97 rounded top arc.
    Lens frame profile now matches the actual lens shape (rectangular body
    + rounded hull cap). Frame pocket uses lens_top_r for the arc slot.
    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
    [sight_housing.scad]
2026-05-27 Add render-cad and 3d-model subagent definitions
    render-cad: generates matplotlib renders of the sight housing from
    the SCAD geometry, with correct arm transform math and lens arc formula.
    3d-model: maintains the OpenSCAD file with authoritative dimension
    tables, lens profile geometry derivation (rect_h = 29.03 mm),
    and coordinate system notes.
    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
2026-05-27 Redesign sight housing: two-post bracket with correct glass geometry
    Replace the diagonal rib arm with a proper reflex sight architecture:
    - rear_post(): tall wall (Y=0) that supports the high edge of the glass
    - front_post(): short ledge (Y=body_d) for the low edge
    - side_rails(): sloped walls connecting the two posts, top edge follows
    the glass tilt angle
    - glass_frame_mount(): lens frame rotated with rotate([90-angle,0,0]) so
    the frame bottom lands front-low and top lands rear-high, matching the
    optical requirement (display light +Z reflects to shooter at -Y)
    Fix lens_frame() geometry: outer arc uses same centre as lens arc with
    radius lens_top_r + wall; lens rect_h correctly compu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
    [sight_housing.scad]
2026-05-27 Fix lens_frame() arc cap: clip cylinder to sliver above outer_rect_h
    Full 360° cylinder was making the frame look circular. Now uses
    intersection() to keep only the ~6.5 mm sagitta above outer_rect_h
    (32.52 mm) for both the outer shell and the glass pocket, matching
    the actual flat-rectangular-with-small-arc-top lens profile.
    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
    [sight_housing.scad]
2026-05-27 Fix lens_frame() pocket: add bottom arc to match actual lens profile
    The lens has arcs on BOTH ends (R16.97, sag 4.97 mm), not just the top.
    The glass pocket previously had a flat-bottomed rectangle that didn't
    match the lens shape, so the lens would only contact the pocket at a
    single centre-bottom point with gaps at the sides.
    Changes:
    - Add bot_rect_z = lens_top_r - sqrt(R²-(w/2)²) = 4.97 mm to derived vars
    - Rectangular pocket now spans only the straight section (z: wall+bot_rect_z
    to wall+lens_rect_h = 7.47–31.53 mm in frame coords)
    - New bottom arc pocket mirrors the top arc cap: cylinder centered at
    wall+lens_top_r, clipped below wall+bot_rect_z, sag ≈ 4.97 mm
    https://clau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
    [sight_housing.scad]
2026-05-27 Add outer bottom arc to lens_frame() shell
    The outer frame profile now mirrors the lens shape on both ends:
    straight section between z=outer_bot_rect_z (6.48 mm) and
    outer_rect_h (32.52 mm), with arc caps (R=R_outer=19.47 mm) clipped
    above/below those tangent lines. Previously the outer shell had a flat
    bottom, making the frame silhouette inconsistent with the lens profile.
    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
    [sight_housing.scad]
2026-05-27 Redesign sight housing to EOTech-style window shroud
    Replace the two-post / side-rail bracket with an enclosed rectangular
    window frame (solid left/right walls, top hood bar, front/rear lower lips).
    The glass_frame_mount is unchanged — combiner glass still tilts at `angle`
    degrees and sits inside the shroud aperture.
    Removes: rear_post, front_post, side_rails modules
    Adds: eotech_shroud module with shroud_wall=3mm, lip_h=10mm
    shroud_h is auto-computed to just enclose the tilted glass frame
    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
    [sight_housing.scad]
2026-05-27 Add OpenSCAD render script (hardware/cad/render.py)
    Drives openscad --render via xvfb-run from three camera angles and
    composites the result into a single PNG using matplotlib + Pillow.
    Replaces the hand-built matplotlib geometry approach with actual SCAD
    output (DeepOcean colour scheme, 900×700 per view).
    Usage: python hardware/cad/render.py [--out PATH]
    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
2026-06-04 Rotate lens to landscape orientation (34 mm horizontal, 24 mm along tilt)
    The physical arc radius (R=16.97 mm) can only span the 24 mm short edge
    (half-chord 12 mm < R). Placing 34 mm horizontal gives a 34×17 mm
    projected aperture at 45° — matching EOTech proportions — vs the previous
    portrait 24×24 mm square aperture.
    - arm_w = lens_h + 2×wall = 39 mm (was lens_w-based, 29 mm)
    - frame_z = lens_w + 2×wall = 29 mm (was lens_h-based, 39 mm)
    - glass_cz uses lens_w/2 for the along-tilt half-span
    - lens_frame() rewritten: arc caps now at LEFT/RIGHT (X) instead of
    TOP/BOTTOM (Z), using the correct half-chord geometry
    - render.py: camera centre Z lowered from 33 to 27 (short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
    [sight_housing.scad]
2026-06-13 Fix arc cap pocket bug: cylinder was centred at frame_y/2, blocking entry face
    The glass pocket arc cap cylinders were centred at Y=frame_y/2=3.87 mm,
    meaning the subtraction only started at Y=2.25 mm. The lens curved ends
    would hit solid material at the entry face (Y=0) and the glass could not
    be inserted. Fix: centre the cylinders at Y=(lens_t+clearance)/2=1.52 mm
    so the pocket spans Y≈0..lens_t+clearance at the arc cap regions,
    matching the straight-section pocket depth.
    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
    [sight_housing.scad]
2026-06-13 Add M2 set-screw retention holes to lens frame for glass assembly
    Two M2×4 set-screw holes (ø2.1 mm, 2.5 mm deep) through the left and
    right arc side walls of the lens frame. Screws bear on the glass arc
    edges, clamping the combiner glass via friction after insertion through
    the entry face. Enables non-destructive assembly and disassembly without
    adhesive.
    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
    [sight_housing.scad]
2026-06-13 Switch to optics-only body: remove USB port, fix PCB pocket clearance
    Electronics (MCU, battery, USB) are now external; the sight body
    houses only the OLED PCB. Changes to screen_body():
    - Remove USB/power port cutout from front wall
    - Add clearance/2 on each side of PCB pocket so PCB drops in freely
    - Update module comment to reflect external-electronics design
    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
    [sight_housing.scad]
2026-06-13 Replace non-ASCII chars in lens_frame retention comments
    Substituted Unicode multiply sign and arrow with ASCII equivalents
    (x and comma) to avoid parser errors in older OpenSCAD builds.
    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
    [sight_housing.scad]
2026-06-13 Merge lens frame arms into shroud side walls
    Added rectangular arms in glass_frame_mount() that extend the lens
    frame from its natural width (arm_w=39mm) all the way through the
    shroud side walls to the body edges. The 4.1mm arms on each side
    close the gap between the floating frame and the walls, making the
    combiner mount a single merged solid with the housing.
    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
    [sight_housing.scad]
2026-06-15 Relicense project under GPL-3.0-or-later
    Replace the MIT/Apache-2.0 dual license with GPL-3.0-or-later: add the
    GPL v3 text as LICENSE, drop LICENSE-APACHE/LICENSE-MIT, update the
    Cargo.toml SPDX field and README, and add the GPL notice disclaimer.
    [body.FCStd]
2026-06-15 Add picatinny mount and STL export script; drop matplotlib render
    Add hardware/cad/picatinny.scad (rail mount) and export_stl.sh helper,
    update sight_housing.scad, and remove the legacy matplotlib render
    script now that the OpenSCAD pipeline is the source of truth.
    [picatinny.scad, sight_housing.scad]
2026-06-19 Replace single-element combiner lens with true birdbath optics
    Swap the tilted curved-meniscus combiner lens for a two-element birdbath:
    a flat 30/70 beamsplitter (1st bounce off the display) and a curved
    collimating mirror (2nd bounce back through the same beamsplitter panel
    to the eye). The fold geometry (mirror_tilt, mirror_R, hit-point
    positions) is fully derived from `angle` via closed-form 2D ray-trace
    formulas, verified to keep the exit ray perfectly level for any angle in
    35-65 degrees and to avoid beamsplitter/mirror frame collisions across
    that whole range.
    The EOTech-style shroud is rebuilt as a boxy two-panel enclosure sized to
    fit both optics frames, with the mirror housing occ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
    [sight_housing.scad]
2026-06-19 Rework birdbath into 45° beamsplitter relay + vertical combiner
    Replace the rejected two-hit-same-panel birdbath with a simpler, exact
    topology: a flat 30/70 beamsplitter fixed at 45° acts as a one-time
    relay near the display (redirects the vertical beam to exactly
    horizontal), and a curved partially-reflective combiner mounted fixed
    vertical (90°) and pushed forward reflects it straight back the way it
    came. Each element is hit exactly once, giving a zero-residual-tilt
    level sightline and a more compact housing (~75.5mm vs ~93mm) than the
    alternative considered.
    - angle pinned at 45°, combiner_tilt fixed at 90° (no more derived
    mirror_tilt sweep)
    - gap1 grown 13->30mm; the untilted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
    [sight_housing.scad]
2026-06-19 birdbath design
    [picatinny.scad, screw_mounts.scad, sight_housing.scad]
2026-06-19 added removable optics pocket
    [sight_housing.scad]
2026-06-28 started pcb design
    [electronics.kicad_pcb, electronics.kicad_sch]
